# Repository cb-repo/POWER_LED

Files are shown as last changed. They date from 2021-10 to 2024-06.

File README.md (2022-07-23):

# POWER LED v1.0

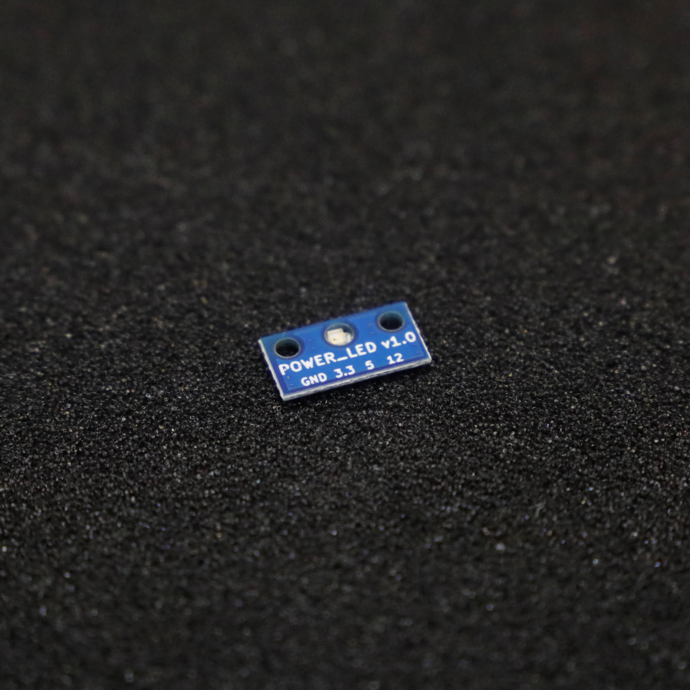
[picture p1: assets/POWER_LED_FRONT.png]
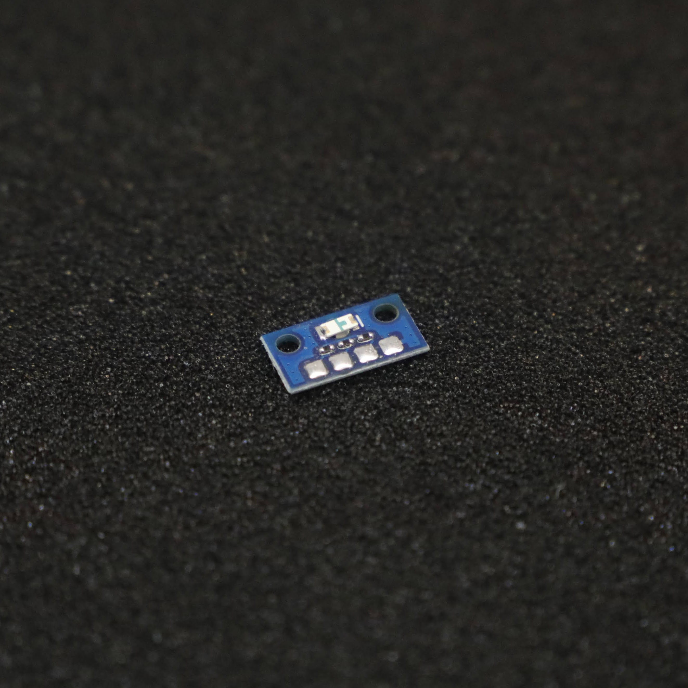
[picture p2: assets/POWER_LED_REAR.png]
 

POWER LED is a unique take on the traditional LED power-indicator design: originally designed for combat robotics, but it's ideal for any application requiring a small easy-to-use panel mount LED. 

Designed and built in [Christchurch, New Zealand ](https://www.google.co.nz/maps/place/Christchurch+New+Zealand) by Connor Benton, visit [cb-technology](https://www.cb-technology.co.nz/) for details.

## FEATURES

- Multiple voltage input options to suit most applications.
- Small form-factor and low-profile design allow the LED to be tucked into tighter areas that simmilar products
- Reverse-mount LED allows for flush and secure mounting in high impact environments. 
- Red LED colour chosen for its visibility.

## SPECIFICATIONS
- **Dimensions:** 14.0x7.5x1.3 mm
- **Weight:** 0.2g *excluding wires or mounting fasteners*
- **Input Voltage:** 3V3, 5V, and 12V options
- **Current Consumption:** 10mA max
- **Mounting Fasteners:** M2

## MOUNTING HOLE PATTERN 
Note: If you do not have an appropriate drill-bit for the two mounting holes, a standard 2[mm] will also work.

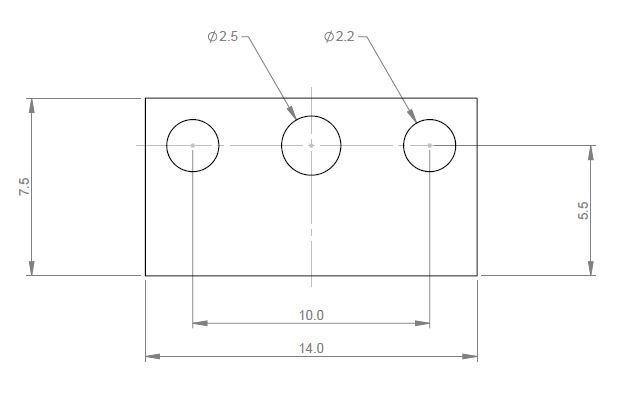
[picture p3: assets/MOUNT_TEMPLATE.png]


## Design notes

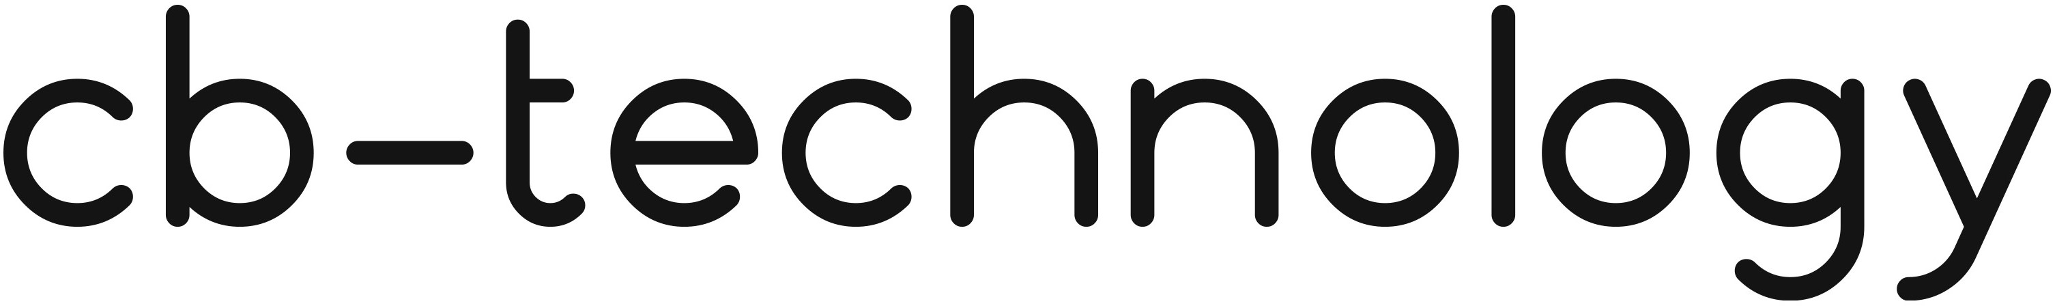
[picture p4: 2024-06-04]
assets/cb-technology.jpg

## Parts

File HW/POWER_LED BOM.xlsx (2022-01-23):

Bill of Materials
Line | Manufacturer | Manufacturer Part Number | Description | Supplier 1 | Supplier P/N | Unit Price | Qty | Cost | Designator
1 | Lite-On | LTST-C230KRKT | Red 631nm 1206 Light Emitting Diodes (LED) ROHS | LCSC | C125107 | $0.03 | 1100 | $29.81 | D1
2 | KAMAYA | RMC10-122JTH | ±5% 0.1W ±200ppm/℃ 1.2kΩ 0402 Chip Resistor - Surface Mount ROHS | LCSC | C323751 | $0.001 | 1100 | $1.10 | R1
3 | KAMAYA | RMC10-331JTH | ±5% 0.1W ±200ppm/℃ 330Ω 0402 Chip Resistor - Surface Mount ROHS | LCSC | C323723 | $0.0025 | 1100 | $2.75 | R2
4 | KAMAYA | RMC10-151JTH | ±5% 0.1W ±200ppm/℃ 150Ω 0402 Chip Resistor - Surface Mount ROHS | LCSC | C323746 | $0.0025 | 1100 | $2.75 | R3
5 | JLC PCB |  | PCB |  |  | $120.68 | 1 | $120.68
6 | Chip Quik Inc. | SMD291AX50T3 | SLDR PASTE NO-CLN SN63/PB37 50G | Digi-Key | SMD291AX50T3-ND | $20.60 | 1 | $20.60
7 | Assembly Labour |  |  |  |  | $30.00 | 20 | $600.00
 |  |  |  |  |  |  |  | $777.69
Approved |  |  | Notes
 | Total Order Cost | $777.69
 | Total Order QTY | 1000
 | Unit Cost | $0.78
 | Unit Sell Price | 2.5
 | Unit Profit | 1.72231
 | Total Profit | 1722.31

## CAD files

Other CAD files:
MECH/RearInsertHolder.SLDPRT
MECH/RearInsertHolder.3MF

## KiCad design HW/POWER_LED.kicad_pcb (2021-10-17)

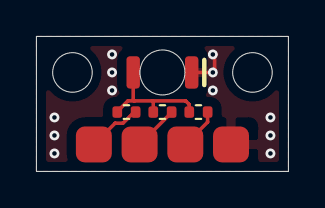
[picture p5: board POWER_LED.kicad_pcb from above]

Board: 2 copper layers, 14.0 x 7.5 mm, 10 parts (0 on the bottom side), 5 nets.

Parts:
D1: LED; DS_Everlight_IR21-21CL110TR8
H1, H2: MountingHole; MountingHole_2.2mm_M2
H3: 12V Pad; TestPoint_Pad_2.0x2.0mm
H4: 5V Pad; TestPoint_Pad_2.0x2.0mm
H5: 3.3V Pad; TestPoint_Pad_2.0x2.0mm
H6: GND Pad; TestPoint_Pad_2.0x2.0mm
R1: 620R; R_0402
R2: 270R; R_0402
R3: 180R; R_0402

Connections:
unnamed: D1.1, H6.1
unnamed: D1.2, R1.1, R2.1, R3.1
unnamed: H3.1, R1.2
unnamed: H4.1, R2.2
unnamed: H5.1, R3.2

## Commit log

2021-10-17 v1.0 Release
    [POWER_LED BOM.xlsx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]
2021-10-23 Sync file structure
    [POWER_LED BOM.xlsx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]
2022-01-23 Update BOM
    [POWER_LED BOM.xlsx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]
2022-02-27 Update Latest Print Files
    [PowerLEDInserHolder.3MF, RearInsertHolder.3MF, RearInsertHolder.SLDPRT]
2022-03-20 Update Datasheet for Release
    [PowerLEDInserHolder.3MF]
2022-06-08 MECH: Sync Latest Revision Files
    [RearInsertHolder.3MF, RearInsertHolder.SLDPRT]
2022-07-23 Update mount template image file name in readme
